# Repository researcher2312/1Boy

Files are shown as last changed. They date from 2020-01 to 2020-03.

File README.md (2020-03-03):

# 1Boy
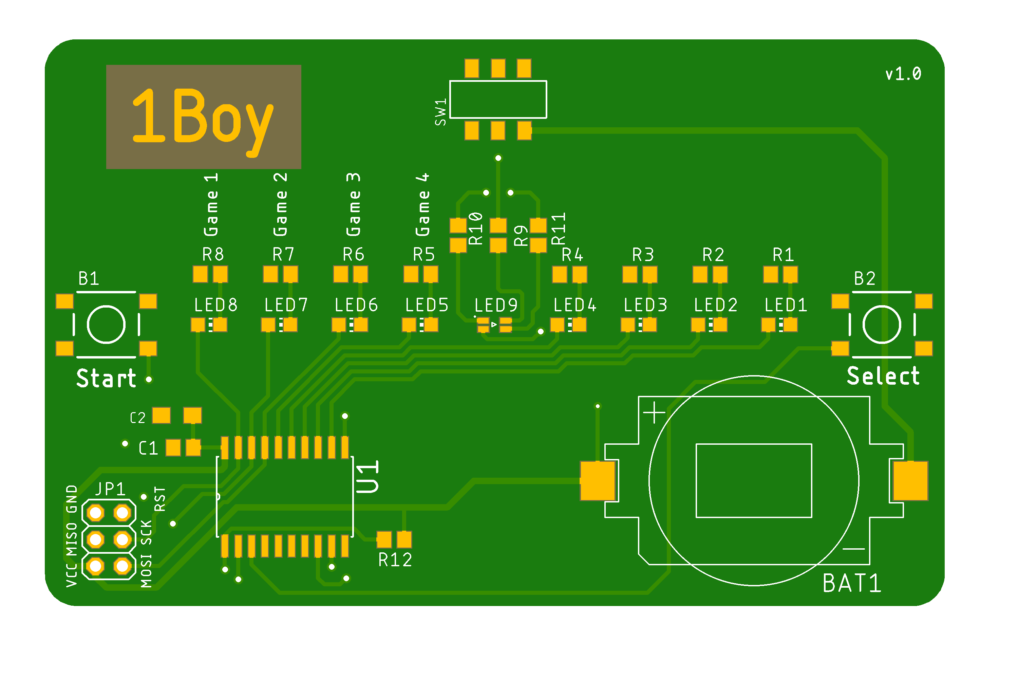
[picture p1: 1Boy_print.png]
Board top view

Project made mainly for fun, but also for microcontroller project on university.
## Hardware
Credit card-sized 'console' based on ATtiny2313 with 1-dimensional screen, two buttons and power switch. 4 leds on the left and on the right are just green, while the middle one is RGB.
Powered by single CR2032 battery.

## Games
**Lowest cost console on market, up to four fun games!**
*Due to lack of memory, currently two games can be played:*

- Pong (1P/2P) - bounce the ball between you and other player or play a duel between your left and right hand
- Memory (1P) - repeat the lengthening sequence of lights

Planned games (after optimalisation of first two):

- Cowboys (2P) - be the fastest hand in the west and press the button faster than the other player after the countdown
- Space shooter (1P) - defeat aliens by pressing buttons in set pattern for each rgb colour

board files created in Cadsoft Eagle

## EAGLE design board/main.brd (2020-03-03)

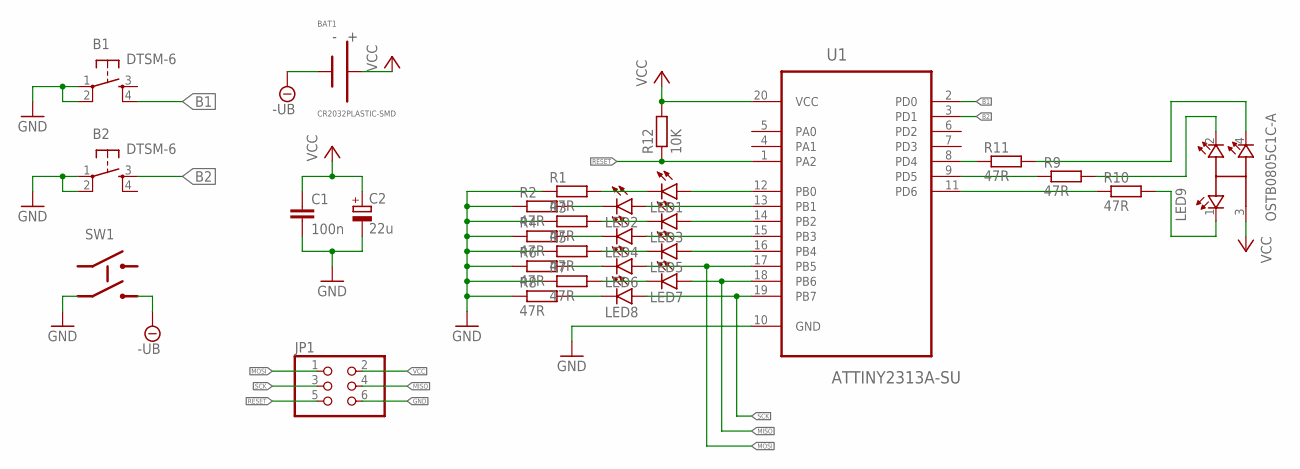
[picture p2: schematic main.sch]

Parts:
B1, B2: DTSM-6
BAT1: CR2032PLASTIC-SMD; BIG-SMD
C1: 100n; C0805
C2: 22u; SMC_A
JP1: PINHD-2X3; 2X03
LED1, LED2, LED3, LED4, LED5, LED6, LED7, LED8: LEDCHIP-LED0805; CHIP-LED0805
LED9: OSTB0805C1C-A; LEDSC200X125X110-4N
R1, R2, R3, R4, R5, R6, R7, R8, R9, R10, R11: 47R; R0805
R12: 10K; R0805
SW1: MSS-22D18; 22D18
U1: ATTINY2313A-SU; SOIC127P1032X265-20N

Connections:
-UB: BAT1.1 (MIN), SW1.6 (OUT2)
B1: B1.4, U1.2 (PD0)
B2: B2.3, U1.3 (PD1)
GND: B1.1, B1.2, B2.1, B2.2, C1.2, C2.-, JP1.6, R1.1, R2.1, R3.1, R4.1, R5.1, R6.1, R7.1, R8.1, SW1.5 (IN2), U1.10 (GND)
MISO: JP1.4, LED7.A, U1.18 (PB6)
MOSI: JP1.1, LED6.A, U1.17 (PB5)
unnamed: LED1.A, U1.12 (PB0)
unnamed: LED1.C, R1.2
unnamed: LED2.A, U1.13 (PB1)
unnamed: LED2.C, R2.2
unnamed: LED3.A, U1.14 (PB2)
unnamed: LED3.C, R3.2
unnamed: LED4.A, U1.15 (PB3)
unnamed: LED4.C, R4.2
unnamed: LED5.A, U1.16 (PB4)
unnamed: LED5.C, R5.2
unnamed: LED6.C, R6.2
unnamed: LED7.C, R7.2
unnamed: LED8.C, R8.2
unnamed: R11.1, U1.8 (PD4)
unnamed: R9.1, U1.9 (PD5)
unnamed: R10.1, U1.11 (PD6)
unnamed: LED9.1, R10.2
unnamed: LED9.2, R9.2
unnamed: LED9.4, R11.2
RESET: JP1.5, R12.1, U1.1 (PA2)
SCK: JP1.3, LED8.A, U1.19 (PB7)
VCC: BAT1.2 (PLUS), C1.1, C2.+, JP1.2, LED9.3, R12.2, U1.20 (VCC)

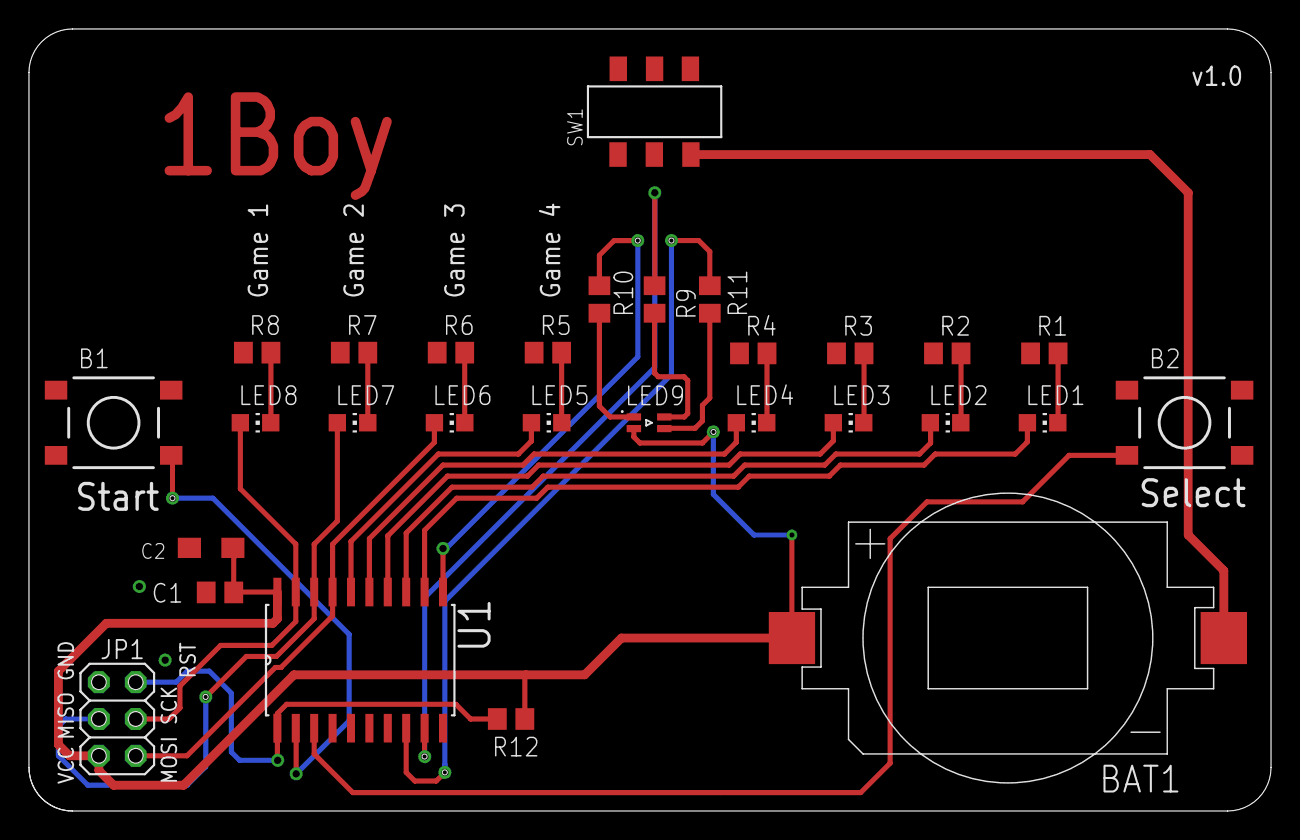
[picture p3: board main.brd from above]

Board: 2 copper layers, 85.7 x 54.0 mm, 29 parts (0 on the bottom side), 28 nets.

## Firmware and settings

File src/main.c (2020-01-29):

#include <avr/io.h>
#include <avr/interrupt.h>
#include "1Boy.h"
#include "1Boy_screen.h"

volatile unsigned int time_ms = 0;
uint8_t previous_button_state [2] = {0};
uint8_t button_state [2] = {0};

extern uint8_t football(uint16_t *game_time);
extern uint8_t memory(uint16_t *game_time);


int main(){
	DDRB |= LED1 | LED2 | LED3 | LED4 | LED5 | LED6 | LED7 | LED8;
	DDRD |= LED_RD | LED_GR | LED_BL;
	PORTD |= BT1 | BT2 | LED_RD | LED_GR | LED_BL;

	TCCR0A |= (1<<WGM01); //CTC mode
	TCCR0B |= (1<<CS00) | (1<<CS01); //64 prescaler, timer on
	OCR0A = 125; //delay, 1 KHz
	TIMSK |= (1<<OCIE0A); //interrupt enable

	sei();

	uint16_t delta_time = 0;
	uint16_t game_time = 0;
	uint8_t game_played = 5;
	uint8_t game_choice = 0;

	uint8_t intro_step = 0;

	while(1){
		if (time_ms > 10){ //100 Hz main loop
			delta_time = time_ms;
			game_time += time_ms;
			time_ms = 0;

			previous_button_state[0] = button_state[0];
			previous_button_state[1] = button_state[1];
			button_state[0] = BT1_DOWN;
			button_state[1] = BT2_DOWN;

			switch(game_played){
			case 0:
				startBlink(500);
				clearScreen();
				addScreenPoint(8-game_choice);
				if (pressedNow(1)){
					++game_choice;
					if(game_choice > 3)
						game_choice = 0;
				}
				if (pressedNow(0)){
					startBlink(0);
					game_time = 0;
					game_played = game_choice + 1;
				}
				break;

			case 1:
				if(football(&game_time) == 1)
					game_played = 0;
				break;

			case 2:
				if(memory(&game_time) == 1)
					game_played = 0;
				break;

			case 3:
				break;

			case 4:
				break;
			case 5:
				if(game_time > (250*intro_step + 250)){
					addScreenPoint(intro_step);
					addScreenPoint(8-intro_step);
					setRGBColor(BLACK + intro_step);
					++intro_step;
					if(intro_step == 8){
						clearScreen();
						game_played = 0;
					}
				}
				break;
			}



			updateScreen(delta_time);
		}
	}
}

uint8_t pressedNow(uint8_t button_number){
	if(button_state [button_number] == 1 && previous_button_state [button_number] == 0)
		return 1;
	else
		return 0;
}

ISR(TIMER0_COMPA_vect){
	++time_ms;
}

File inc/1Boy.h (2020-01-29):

/*
 * 1Boy.h
 *
 *  Created on: 30 gru 2019
 *      Author: researcher
 */

#ifndef INC_1BOY_H_
#define INC_1BOY_H_

#define LED1 (1<<PB7)
#define LED2 (1<<PB6)
#define LED3 (1<<PB5)
#define LED4 (1<<PB4)
#define LED5 (1<<PB3)
#define LED6 (1<<PB2)
#define LED7 (1<<PB1)
#define LED8 (1<<PB0)

#define LED_RD (1<<PD6)
#define LED_GR (1<<PD5)
#define LED_BL (1<<PD4)

#define LED_RD_OFF PORTD |= LED_RD
#define LED_GR_OFF PORTD |= LED_GR
#define LED_BL_OFF PORTD |= LED_BL

#define LED_RD_ON PORTD &= ~LED_RD
#define LED_GR_ON PORTD &= ~LED_GR
#define LED_BL_ON PORTD &= ~LED_BL

#define BT1 (1<<PD0)
#define BT2 (1<<PD1)

#define BT1_DOWN !(PIND & BT1)
#define BT2_DOWN !(PIND & BT2)

uint8_t pressedNow(uint8_t button_number);

extern uint16_t delay;
extern volatile unsigned int time_ms;

#endif /* INC_1BOY_H_ */

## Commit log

2020-01-11 configured the timer and interrupts
2020-01-11 changed frequency of interrupt to 1KHz
2020-01-11 added button pressing
2020-01-11 added driver for basic screen operations
2020-01-21 added first game and button state functions
2020-01-28 added game selection stage
2020-03-03 added board files
    [main.brd, main.sch]
